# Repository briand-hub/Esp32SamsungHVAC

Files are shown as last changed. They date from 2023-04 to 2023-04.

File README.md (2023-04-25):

# Briand's SAMSUNG HVAC controller MWR-WH000

Open Source project under GPL3 [LICENSE](LICENSE).

No warranty on circuit or software, do it for educational puroposes. 

#### How to use?

Just edit [Settings](main/Settings.hxx) file entering your own SSID and Password, build circuit and cable and test. 
Always be safe when using electronics and power sources!

## Intro

Samsung MWR-WRH00 with wired remote wall mounted command (D64 type) needs to be wifi-enabled to use with HomeAssistant.

Found protocol on https://github.com/DannyDeGaspari/Samsung-HVAC-buscontrol

2-wire RS485 protocol. To open remote command simply push it up. Will find 4 pin connector (TYPE ????)

```
	male (to remote PCB) (* = attach clip, view from top)

	| | * | |
	| | * | |
	| | * | |
	 | | | |
     1 2 3 4

    female (from wall) (* = attach clip, view from top)

	| | | | |
	| | * | |
	| | * | |
	 1 2 3 4

	1) ORANGE wire, V1, +Vcc 12VDC 
	2) YELLOW wire, V2, GND
	3) RED wire, F3, RS485 port A
	4) BLUE wire, F4, RS485 port B
```

## Voltage adapter (12VDC to 5VDC)

Need to change 12V to 5.1V for ESP32 using zener diode. Circuit:

```
+12V o----| R |------*-------o +5.1V
					 |
					___
					/ \ Zener 5.1V
					 |
					 |
GND  o---------------*-------o GND
```

Calculations, known that ESP32 consumes about 240mA in active mode. Round to 300mA. Zener consumes about 5mA to work.
Voltage across R is Vr, voltage across zener is Vz = 5.1V
	Vr + Vz = 12V => Vr = 12-5.1 = 6.9V
	
R has voltage 6.9V and current is 305mA. So R = V/I = 6.9/0.305 = 22.6ohm so R = 22ohms according to standards. 
R should support 6.9V*0.305A = 2.1W
Zener should support  5.1V*0.305A = 1.55W

Other way: using 7805 regulator, supports up to 1A current.

```	 ________
	|	     |		1) Input, 12V
	| L7805  |		2) GND
	|________|		3) Output, 5V
	 |  |  |
	 |  |  |
	 |  |  |
     1  2  3

+12V o--->|----*---(1) 7805 (3)----*-----o +5V
		D1	   |	   (2)         |
			  ---		|         ---
			  ---C1	    |		  ---C2
			   |	    | 		   |
GND  o---------*--------*----------*-----o GND

```

D1 is 1N4007 (drops 0.6-1V) and helps 7805 work better. C1 is 10uF electrolitic and C2 is 1uF electrolitic (both 25V or C1 25V and C2 10V). Capacitors are **NOT OPTIONAL**.

**NOTE**: Tests shown a high temperature of 7805 reached after a while! Be careful and use a heat sink! Or pass by a 7809 before 7805 so dropped voltage transformed in heat will be less.

## ESP32 Pinout

ESP32 (WeMos Lolin D32) has 3 UARTs (UART0 is monitor, 1 free/unknown, 2 is completely free). IDF Framework based on FreeRTOS allows using an UART hardware port with *any* pin! However RS485 protocol is designed on RTS pin high (RequestToSend) when transmitting, so for this pin a low-level boot time pin is required. Chosen pins are:

GPIO17 as TX pin
GPIO18 as RTS pin
GPIO16 as RX pin

To change pins and port see main.cpp method Briand SamsungHvac->Initialize 
ESP32 will be a sniffer between machine and wired remote in order to be able to use both manual, wall mounted, remote and WiFi. Will need an RS485/TTL 5V converter (can find cheap on Amazon but I suggest to buy a DIP8 SN75176BP, I found that is the best one!).
Setup:

**Cable**

```
		| | | | 
		| | | | 
		| | | | 
		1 2 3 4
		| | | |
		o----------- Orange, V1, +12VDC ---> to 7805 input
		| o--------- Yellow, V2, GND    ---> to 7805 ground
		| | o------- Red, F3, Signal    ---> to A port on RS485/TTL
		| | | o----- Blue, F4, Signal   ---> to B port on RS485/TTL
		| | | |
		1 2 3 4
		| | | | 
 		| | | | 
 		| | | | 
```

## RS485/TTL to ESP32

```
Pin DI/R => to RX (ESP GPIO16)
Pin DE => to RTS  (ESP GPIO18)
Pin RE => to RTS (ESP GPIO18)
Pin RO/D => to TX (ESP GPIO17)

VCC => +5 VDC from 7805
GND => GND
A => cable (red) to A
B => cable (blue) to B
```

## Final circuit

#### Materials needed

* 1x Diode 1N4001 or 1N4007 (or 3x to decrease heat)
* 1x Voltage regulator with output of 5V (7805CV, LM2940CT5 or similar)
* ESP32 
* SN75176BP (best!) or MAX485
* 1x Electrolitic capacitor 10uF 
* 1x Electrolitic capacitor 1uF
* 1x heatsinker for TO-220 voltage regulator

Optional:

* 1x 3mm green Led 
* 1x 150ohm Resistor 
* TVS bipolar diode (RS485 IC input between port A to ground and between port B to ground for ESD/overvoltage protection)

See circuit in Fritzing model (Schema view) or the PNG file.

Calculations:

* LED 3mm green 2V 20mA 5V-2V = 3V and so R = V/I = 3V/0,02 = 150ohm with P = 3V*0,02 = 0,06WW

## Web server commands and API

**Parameters**

* temp : must be integer (ex. 22)
* mode : must be one of: "cool", "fan", "dry", "heat", "auto"
* fan : must be one of: "min", "max", "mid", "auto"
* power : must be "on" or "off"

**Get current HVAC status**

http://<IP>:<PORT>/

returns the current status in JSON

Response:

```
{ "power": "off", "mode": "cool", "temp": 24, "fan": "max", "ha_status": "OK", "ha_active": true }
```

**Change HVAC status**

http://<IP>:<PORT>/SetStatus?temp=<int>&mode=<mode>&fan=<fan>&power=<power>

Sample request/response:

```
http://<IP>:<PORT>/SetStatus?mode=cool&power=on
Power changed to ON
Mode changed to COOL
```

**Restart/reboot**

http://<IP>:<PORT>/RestartEsp

**Monitor log**

http://<IP>:<PORT>/Log

*not implemented yet*

## Test result

All commands are received/sent successfully. However sometimes an error E607 appears on the wall mounted remote when a command is sent and sometimes is not correctly applied.
Possible solutions:

* Setting RX buffer to 0 so no buffering will be made? *No, not allowed!*
* Adding 50ms delay before sending the message through serial when the "mark" is reached qould help? *Did not resolve*
* Play with rx threshold values? *Did not resolve*

On circuit L7805CV model seems to have lot of heat. Needs a heat sink. However another (and implemented solution) is to add 2 more 2N4001 in series to D1 in order to have a lower voltage in input. This solves the heat problem. 

Other unsuccessful test done was adding a 2-step LDO: L7809 before L7805 however this seems to led insufficient amperes to ESP32 meaning no working system at all.

## Protocol

RS485 Protocol description **CREDITS: https://github.com/DannyDeGaspari/Samsung-HVAC-buscontrol**. Took and reported there some needed texts.

*Serial communication settings used on the bus are 2400 baud, 8E1 **(8 bit, even parity, 1 bit stop)**. The wired remote control is the master, the indoor units are the slaves. The wired remote control send commands as a message of 14 bytes. The units respond with a similar message with the same length. The protocol can be described as follows:*

<start> <src> <dst> <cmd> <data: 8 bytes> <chksum> <end>

With:
Byte   Identifier   Comments
----------------------------
1      Start  : start of message (0x32)
2      Src    : Source address
3      Dst    : Destination address
4      Cmd    : Command byte
5-12   Data   : Data is always 8 bytes in length, unused bytes will be zero
13     Chksum : Checksum of message which is the XOR of bytes 2-12
14     End    : end of message (0x34)

*In my case the address of the wired remote control is 0x84* => **For me too!**
*the address of my 2 indoor units are 0x20 and 0x21* => **For me too! However I have just one, 0x20**

An example communication can look like this (all values are hex and xx represent any value):

```
Command:
32 84 20 53 xx xx xx xx xx xx xx xx xx 34
Reply:
32 20 84 53 xx xx xx xx xx xx xx xx xx 34
```

### Command tables

All values of the commands and bit group values in the following tables are in hexadecimal notation.
The bits that are not described in the following tables are zero and the function of those bits are unknown.

### Command A0

Change settings command, by exception the unit replies with command 50, all other commands are replied with the same command identifier.
This is the command to be used when the settings of the HVAC unit needs to be changed.

| Data byte | Settings |
| :---: | :--- |
| 1 | <p>bit 4-0 : 0x1a = blade swing up/down<br>0x1f = blade swing off</p> |
| | bit 5 : sleep |
| 2 | 0 |
| 3 | bit 4-0 : temperature setting |
| | <p>bit 7-5 : fan speed<br>0 = auto<br>2 = low<br>4 = medium<br>5 = high</p> |
| 4 | <p>bit 2-0 : mode<br>0 = auto<br>1 = cool<br>2 = dry<br>3 = fan<br>4 = heat</p> |
| | bit 5 : reset "clean filter" message |
| 5 | <p>bit 7-0 : on/off<br>c4 = switch off<br>f4 = switch on</p> |
| 6 | 0 |
| 7 | <p>bit 3-0 : set blade position<br>0 = closed<br>1 = open smallest<br>2 = mid positions<br>7 = open max</p> |
| | bit 4 : set blade position |
| | bit 5 : quiet mode |
| 8 | 0 |

### Command 52

This command is an information request. The bytes in the command are all zeroes, the reply to this command is described below:

| Data byte | Settings |
| :---: | :--- |
| 1 | bit 5-0 : set temperature - 9 |
| | bit 6 : always set to '1' ? |
| 2 | bit 5-0 : room temperature - 9 |
| | bit 6 : always set to '1' ? |
| 3 | bit 5-0 : output air temperature - 9 |
| | bit 6 : always set to '1' ? |
| 4 | <p>bit 2-0 : fan speed<br>0 = auto<br>2 = low<br>4 = medium<br>5 = high</p> |
| | <p>bit 7-3 : blade swing<br>1A = swing up/down<br>1F = blade swing off</p> |
| 5 | <p>bit 3-0 : 1 = wired control<br>2 = remote control</p> |
| | bit 4 : 1 = defrost on |
| | <p>bit 7 : 0 = power is off<br>1 = power in on</p> |
| 6 | bit 4 : 1 = filter needs cleaning |
| 7 | 0 |
| 8 | bit 5-0 : another temperature - 9 |
| | bit 6 : always set to '1' ? |

### Command 53

This command is an information request. The bytes in the command are all zeroes, the reply to this command is described below:

| Data byte | Settings |
| :---: | :--- |
| 1 | 0 |
| 2 | 0 |
| 3 | 0 |
| 4 | 0 |
| 5 | <p>bit 7-0 : 0 = blade swing off<br>1A = blade swing up/down</p> |
| 6 | 0 |
| 7 | 0 |
| 8 | <p>bit 2-0 : mode<br>0 = auto<br>1 = cool<br>2 = dry<br>3 = fan<br>4 = heat</p> |

### Command 54

This command is an information request. The bytes in the command are all zeroes, the reply to this command is described below:

| Data byte | Settings |
| :---: | :--- |
| 1 | contains value 21, meaning unknown |
| 2 | <p>bit 3-0 : blade position when swing is off<br>0 = closed<br>1 = open smallest<br>2 = mid positions<br>7 = open max</p> |
| | <p>bit 4 : 0 = blade swing off<br>1 = blade swing up/down</p> |
| 3 | 1E : meaning unknown |
| 4 | 0 |
| 5 | 0 |
| 6 | unknown |
| 7 | 0 |
| 8 | 0 |

### Command 64

This command is the temperature information command to the unit, the reply to this command is described below:

| Data byte | Settings |
| :---: | :--- |
| 1 | contains value 20 for command and reply, meaning unknown |
| 2 | <p> command and reply: bit 0: used temperature for regulation<br>0 = use internal temperature<br>1= use wired remote temperature</p> |
| 3 | command: wired remote temperature value high byte |
| | reply: used temperature value high byte |
| 4 | command: wired remote temperature value low byte |
| | reply: used temperature value low byte |
| 5 | reply: unit temperature value high byte |
| 6 | reply: unit temperature value low byte |
| 7 | 0 |
| 8 | 0 |

The temperature in degrees is calculated as follows: 
```
(<high byte> * 256 + <low byte> - 553) / 10
```

### Other commands

Other commands seen on the link are: 63, 70, 71, 83, D1.
The meaning of these commands and replies are unknown.
Be careful with trying other commands because it is possible that there exist commands that have impact on the flash memory contents of the unit and may brick the memory contents of the unit.

## Circuit schema and picture

Circuit schematics

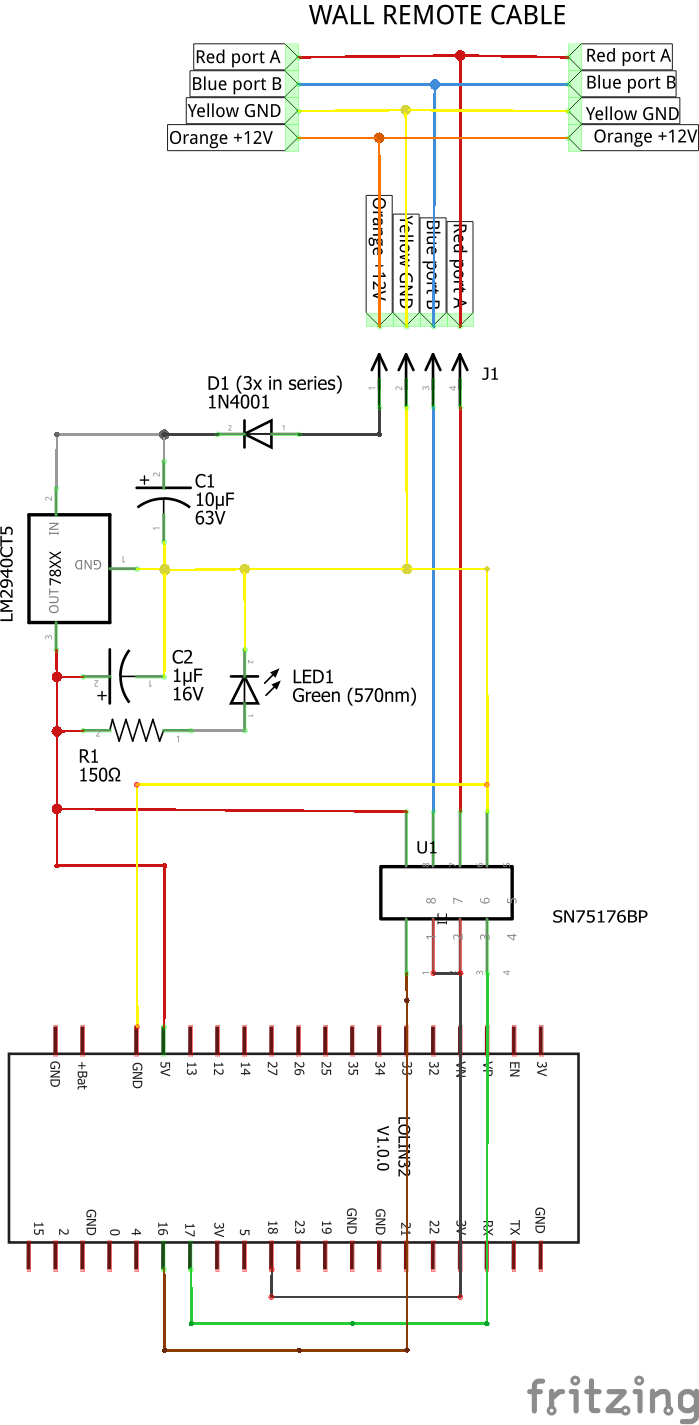
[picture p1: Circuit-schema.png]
Circuit diagram


The first working prototype

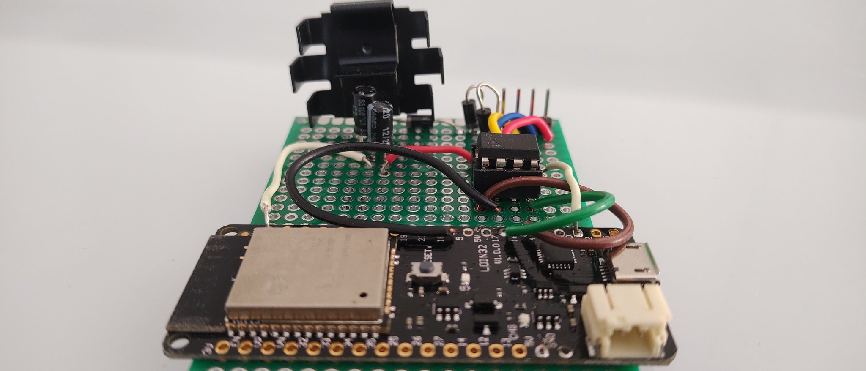
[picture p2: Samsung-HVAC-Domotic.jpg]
Demo


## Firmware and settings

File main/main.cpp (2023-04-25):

/** Copyright (C) 2023 briand (https://github.com/briand-hub)

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
    You should have received a copy of the GNU General Public License
    along with this program.  If not, see <http://www.gnu.org/licenses/>.
*/

#include "Common.hxx"
#include "BriandLibEsp32IDF.hxx"
#include "BriandSamsungHvac.hxx"
#include "Settings.hxx"

/* Early declarations */
void SerialReadWriteTask(void* taskArg);
esp_err_t ServeStatus(httpd_req_t* req);
esp_err_t ServeSetStatus(httpd_req_t* req);
esp_err_t ServeRestart(httpd_req_t* req);
void Reboot();

/* Declarations */

const httpd_uri uriStatus {
	.uri = "/",
	.method = HTTP_GET,
	.handler = ServeStatus
};

const httpd_uri uriSetStatus {
	.uri = "/SetStatus",
	.method = HTTP_GET,
	.handler = ServeSetStatus
};

const httpd_uri uriRestart {
	.uri = "/RestartEsp",
	.method = HTTP_GET,
	.handler = ServeRestart
};

httpd_handle_t serverHandle = NULL;
TaskHandle_t serialTaskHandle = NULL;
TaskHandle_t wifiTaskHandle = NULL;
unique_ptr<Briand::SamsungHvac> SamsungHvac = nullptr;
unique_ptr<Briand::WifiManager> wifi = nullptr;

const esp_vfs_spiffs_conf_t spiffsConfiguration = {
	.base_path = "/spiffs",
	.partition_label = NULL,
	.max_files = 5,
	.format_if_mount_failed = true
};

/********************************************/
/*					PROGRAM					*/
/********************************************/

// Required extern "C" for C++ use WITH IDF!
extern "C" void app_main() {
	try {
		// Set BuiltIn LED 
		gpio_set_direction(GPIO_NUM_5, GPIO_MODE_OUTPUT);

		// UNbuffer stdout
		setvbuf(stdout, NULL, _IONBF, 0);

		// Common for error testing
		esp_err_t ret;

		// Initialize the NVS
		ESP_LOGI(LOG_TAG, "Initializing NVS");

		ret = nvs_flash_init();
		if (ret == ESP_ERR_NVS_NO_FREE_PAGES || ret == ESP_ERR_NVS_NEW_VERSION_FOUND) {
			ESP_ERROR_CHECK(nvs_flash_erase());
			ret = nvs_flash_init();
		}
		ESP_ERROR_CHECK(ret);
		ESP_LOGI(LOG_TAG, "NVS Initialized.");

		// Initialize SPIFFS
		ESP_LOGI(LOG_TAG, "Initializing SPIFFS");

		// Use settings defined above to initialize and mount SPIFFS filesystem.
		// Note: esp_vfs_spiffs_register is an all-in-one convenience function.
		ret = esp_vfs_spiffs_register(&spiffsConfiguration);
		if (ret == ESP_OK) {
			ESP_LOGI(LOG_TAG, "SPIFFS Initialized.");
		}
		else {
			ESP_LOGE(LOG_TAG, "**** SPIFFS initialization failed! ERROR is: %s", esp_err_to_name(ret));
		}

		// Initialize WiFi handler
		wifi = make_unique<Briand::WifiManager>();
		wifi->ConnectStation(WIFI_ESSID, WIFI_PASSW);

		// Start web server
		ESP_LOGI(LOG_TAG, "Starting WebServer on port %d", WEB_SERVER_PORT);
		httpd_config serverConfig = HTTPD_DEFAULT_CONFIG();
		serverConfig.server_port = WEB_SERVER_PORT;
		serverConfig.stack_size = WEB_SERVER_STACK;
		serverConfig.lru_purge_enable = true;
		ret = httpd_start(&serverHandle, &serverConfig);
		if (ret == ESP_OK) {
			// Set URI handlers
			ESP_LOGI(LOG_TAG, "Registering URI handlers");
			httpd_register_uri_handler(serverHandle, &uriStatus);
			httpd_register_uri_handler(serverHandle, &uriSetStatus);
			httpd_register_uri_handler(serverHandle, &uriRestart);
		}
		else {
			ESP_LOGE(LOG_TAG, "**** Failed to start WebServer! ERROR IS: %s", esp_err_to_name(ret));
		}

		ESP_LOGI(LOG_TAG, "Starting Serial");
		
		SamsungHvac = make_unique<Briand::SamsungHvac>();
		SamsungHvac->Initialize(UART_NUM_2, 0, GPIO_NUM_17, GPIO_NUM_16, GPIO_NUM_18, UART_PIN_NO_CHANGE);
		ESP_LOGI(LOG_TAG, "Serial ready.");

		// Start task for serial read/write with max priority in specific core
		xTaskCreatePinnedToCore(SerialReadWriteTask, "SerialTask", 4096, NULL, 1, &serialTaskHandle, 1);
	} 
	catch(const exception& e) {
		ESP_LOGE(LOG_TAG, "**** Exception caught: %s\n", e.what());
	}

	fflush(stdout);
}

esp_err_t ServeStatus(httpd_req_t* req) {
	httpd_resp_set_type(req, "application/json");
	
	auto currentStatus = SamsungHvac->GetSamsungStatus();
	char conversionBuffer[3];

	unique_ptr<string> json = make_unique<string>();
	json->append("{ ");
	json->append("\"power\": \"");
	json->append(Briand::SamsungHvac::PowerToString(currentStatus.Power));
	json->append("\", \"mode\": \"");
	json->append(Briand::SamsungHvac::ModeToString(currentStatus.Mode));
	json->append("\", \"temp\": ");
	json->append(itoa(currentStatus.Temperature, conversionBuffer, 10));
	json->append(", \"fan\": \"");
	json->append(Briand::SamsungHvac::FanSpeedToString(currentStatus.Fan));

	// some vars that helps in HomeAssistant
	json->append("\", \"ha_status\": \"OK\", \"ha_active\": true");

	json->append(" }");

	return httpd_resp_send(req, json->c_str(), json->length());
}

void SerialReadWriteTask(void* taskArg) {
	while (1) {
		SamsungHvac->DoSerialWork();
		vTaskDelay(50 / portTICK_PERIOD_MS);
	}
}

esp_err_t ServeSetStatus(httpd_req_t* req) {
	httpd_resp_set_hdr(req, "Content-Type", "text/plain");
	httpd_resp_set_status(req, "200 OK");

	// Get current status
	auto newStatus = SamsungHvac->GetSamsungStatus();
	
	// Get query params and change the status
	int qsBufLen = httpd_req_get_url_query_len(req) + 1;
	char qsBuffer[qsBufLen];

	if (httpd_req_get_url_query_str(req, qsBuffer, qsBufLen) != ESP_OK) {
		httpd_resp_set_type(req, "text/plain");
		return httpd_resp_send(req, "No argument received!", strlen("No argument received!"));
	}

	char param[32] = { 0 };

	if (httpd_query_key_value(qsBuffer, "power", param, sizeof(param)) == ESP_OK) {
		if (strcmp(param, "on") == 0) {
			newStatus.Power = Briand::SamsungHvacPower::On; 
			httpd_resp_sendstr_chunk(req, "Power changed to ON\r\n");
		} 
		else if (strcmp(param, "off") == 0) {
			newStatus.Power = Briand::SamsungHvacPower::Off;
			httpd_resp_sendstr_chunk(req, "Power changed to OFF\r\n");
		}
		else {
			httpd_resp_sendstr_chunk(req, "Power INVALID! valid values = on|off but received = ");
			httpd_resp_sendstr_chunk(req, param);
			httpd_resp_sendstr_chunk(req, "\r\n");
		}
	}

	bzero(static_cast<void*>(param), 32);

	if (httpd_query_key_value(qsBuffer, "fan", param, sizeof(param)) == ESP_OK) {
		if (strcmp(param, "auto") == 0) {
			newStatus.Fan = Briand::SamsungHvacFanSpeed::FanAuto;
			httpd_resp_sendstr_chunk(req, "Fan changed to AUTO\r\n");
		} 
		else if (strcmp(param, "max") == 0) {
			newStatus.Fan = Briand::SamsungHvacFanSpeed::FanMax;
			httpd_resp_sendstr_chunk(req, "Fan changed to MAX\r\n");
		} 
		else if (strcmp(param, "mid") == 0) {
			newStatus.Fan = Briand::SamsungHvacFanSpeed::FanMid;
			httpd_resp_sendstr_chunk(req, "Fan changed to MID\r\n");
		} 
		else if (strcmp(param, "min") == 0) {
			newStatus.Fan = Briand::SamsungHvacFanSpeed::FanMin;
			httpd_resp_sendstr_chunk(req, "Fan changed to MIN\r\n");
		} 
		else {
			httpd_resp_sendstr_chunk(req, "Fan INVALID! valid values = auto|max|mid|min but received = ");
			httpd_resp_sendstr_chunk(req, param);
			httpd_resp_sendstr_chunk(req, "\r\n");
		}
	}

	bzero(static_cast<void*>(param), 32);

	if (httpd_query_key_value(qsBuffer, "mode", param, sizeof(param)) == ESP_OK) {
		if (strcmp(param, "auto") == 0) {
			newStatus.Mode = Briand::SamsungHvacMode::Auto;
			httpd_resp_sendstr_chunk(req, "Mode changed to AUTO\r\n");
		} 
		else if (strcmp(param, "cool") == 0) {
			newStatus.Mode = Briand::SamsungHvacMode::Cool;
			httpd_resp_sendstr_chunk(req, "Mode changed to COOL\r\n");
		} 
		else if (strcmp(param, "dry") == 0) {
			newStatus.Mode = Briand::SamsungHvacMode::Dry;
			httpd_resp_sendstr_chunk(req, "Mode changed to DRY\r\n");
		} 
		else if (strcmp(param, "fan") == 0) {
			newStatus.Mode = Briand::SamsungHvacMode::Fan;
			httpd_resp_sendstr_chunk(req, "Mode changed to FAN\r\n");
		} 
		else if (strcmp(param, "heat") == 0) {
			newStatus.Mode = Briand::SamsungHvacMode::Heat;
			httpd_resp_sendstr_chunk(req, "Mode changed to HEAT\r\n");
		} 
		else {
			httpd_resp_sendstr_chunk(req, "Mode INVALID! valid values = auto|cool|dry|heat|fan but received = ");
			httpd_resp_sendstr_chunk(req, param);
			httpd_resp_sendstr_chunk(req, "\r\n");
		}
	}

	bzero(static_cast<void*>(param), 32);

	if (httpd_query_key_value(qsBuffer, "temp", param, sizeof(param)) == ESP_OK) {
		int temp = atoi(param);
		if (temp >= 0 && temp <= 40) {
			newStatus.Temperature = temp;
			httpd_resp_sendstr_chunk(req, "Temperature changed to: ");
			char ntBuf[16] = { 0 };
			itoa(temp, ntBuf, 10);
			httpd_resp_sendstr_chunk(req, ntBuf);
			httpd_resp_sendstr_chunk(req, "\r\n");
		}
		else {
			httpd_resp_sendstr_chunk(req, "Temperature INVALID! valid values = <int> but received = ");
			httpd_resp_sendstr_chunk(req, param);
			httpd_resp_sendstr_chunk(req, "\r\n");
		}
	}
	
	SamsungHvac->RequestSamsungChangeStatus(newStatus);

	//return httpd_resp_send(req, NULL, 0);
	return httpd_resp_sendstr_chunk(req, NULL);
}

esp_err_t ServeRestart(httpd_req_t* req) {
	httpd_resp_set_type(req, "text/plain");
	httpd_resp_send(req, "REBOOTING!", strlen("REBOOTING!"));
	httpd_resp_send(req, NULL, 0);
	Reboot();

	return ESP_OK;
}

void Reboot() {
	ESP_LOGI(LOG_TAG, "\n\n### Restarting ESP.\n\n");
	try {
		ESP_LOGI(LOG_TAG, "### Stopping serial...");
		if (serialTaskHandle != NULL) vTaskDelete(serialTaskHandle);
		SamsungHvac.reset();
		ESP_LOGI(LOG_TAG, "### Stopping wifi...");
		if (wifiTaskHandle != NULL) vTaskDelete(wifiTaskHandle);
		if (wifi != nullptr) wifi->DisonnectStation();
		ESP_LOGI(LOG_TAG, "### Stopping webserver...");
		if (serverHandle != NULL && httpd_stop(serverHandle) != ESP_OK) ESP_LOGW(LOG_TAG, "**** Stopping webserver failed!");
	}
	catch(const exception& e) {
		ESP_LOGE(LOG_TAG, "**** Exception caught while restarting: %s\n", e.what());
	}

	ESP_LOGI(LOG_TAG, "### Restarting in 1 second.");
	fflush(stderr);
	fflush(stdout);
	vTaskDelay(1000 / portTICK_PERIOD_MS);

	esp_restart();
}

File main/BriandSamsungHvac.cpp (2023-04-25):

/** Copyright (C) 2023 briand (https://github.com/briand-hub)

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
    You should have received a copy of the GNU General Public License
    along with this program.  If not, see <http://www.gnu.org/licenses/>.
*/

#include "BriandSamsungHvac.hxx"

/** SamsungHvacState class **/

Briand::SamsungHvacState::SamsungHvacState() {
	this->Fan = Briand::SamsungHvacFanSpeed::UNKNOWN;
	this->Mode = Briand::SamsungHvacMode::UNKNOWN;
	this->Power = Briand::SamsungHvacPower::UNKNOWN;
	this->Temperature = 0x00;
}

/** SamsungHvac class **/

Briand::SamsungHvac::SamsungHvac() {
	this->_stateChangeQueue = make_unique<queue<Briand::SamsungHvacState>>();
	this->_currentState = make_unique<Briand::SamsungHvacState>();
	this->_uartPort = UART_NUM_2;
}

Briand::SamsungHvac::~SamsungHvac() {
	// Wait for a mutex
	unique_lock<mutex> locker(this->_mutexStatus);
	this->_currentState.reset();

	// Wait for a mutex
	unique_lock<mutex> locker2(this->_mutexQueue);
	this->_stateChangeQueue.reset();
	
	// Uninstall driver and release UART port
	if (uart_is_driver_installed(this->_uartPort)) {
		uart_flush(this->_uartPort);
		uart_flush_input(this->_uartPort);
		uart_driver_delete(this->_uartPort);
	}
}

void Briand::SamsungHvac::Initialize(
	const uart_port_t& port /* = UART_NUM_2 */
	, const int& initrAllocFlags /* = 0 */
	, const int& txPin /* = UART_PIN_NO_CHANGE */
	, const int& rxPin /* = UART_PIN_NO_CHANGE */
	, const int& rtsPin /* = UART_PIN_NO_CHANGE */
	, const int& ctsPin /* = UART_PIN_NO_CHANGE */
	, const string& spiffsLogFilePath /* = "" */
) {
	this->_logFileName = spiffsLogFilePath;

	// Prepare configuration for Samsung Hvac. 
	// Baud is 2400, 8 bit data, partity even, 1 bit stop
	const uart_config_t uartConfiguration = {
		.baud_rate = 2400,							// Samsung HVAC default RS485 Baud rate
		.data_bits = UART_DATA_8_BITS,				// 8 bit data
		.parity = UART_PARITY_EVEN,					// Parity even
		.stop_bits = UART_STOP_BITS_1,				// 1 stop bit
		.flow_ctrl = UART_HW_FLOWCTRL_DISABLE,		// took from ESP IDF docs and samples
		.rx_flow_ctrl_thresh = 14,					// should not be necessary with no hw flow control...
		.source_clk = UART_SCLK_APB					// meaning default value
	};

	this->_uartPort = port;

	ESP_LOGI("Briand::SamsungHvac", "Installing UART driver on port %d", port);

	// According to documentation and example RX bufsize is 127*2 (?? with other values is not working) and TX has no buffer
	ESP_ERROR_CHECK(uart_driver_install(port, 127*2, 0, 0, NULL, initrAllocFlags));
	ESP_ERROR_CHECK(uart_param_config(port, &uartConfiguration));

	// PIN Setting
	ESP_ERROR_CHECK(uart_set_pin(port, txPin, rxPin, rtsPin, ctsPin));
	ESP_LOGI("Briand::SamsungHvac", "UART driver installed on port %d with pins (TX,RX,RTS,CTS) = (%d,%d,%d,%d)", port, txPin, rxPin, rtsPin, ctsPin);

	// Set RS485 half duplex mode
    ESP_ERROR_CHECK(uart_set_mode(port, UART_MODE_RS485_HALF_DUPLEX));
	ESP_LOGI("Briand::SamsungHvac", "UART%d in RS485 HalfDuplex mode", port);

    // Set read timeout of UART TOUT feature
    ESP_ERROR_CHECK(uart_set_rx_timeout(port, 3)); // 3.5T * 8 = 28 ticks, TOUT=3 -> ~24..33 ticks
	ESP_LOGI("Briand::SamsungHvac", "UART%d with rx timeout set to 3.", port);

	ESP_LOGI("Briand::SamsungHvac", "UART%d READY!", port);
}

const Briand::SamsungHvacState Briand::SamsungHvac::GetSamsungStatus() {
	SamsungHvacState state;

	// Wait for a mutex
	unique_lock<mutex> locker(this->_mutexStatus);

	state.Power = this->_currentState->Power;
	state.Fan = this->_currentState->Fan;
	state.Mode = this->_currentState->Mode;
	state.Temperature = this->_currentState->Temperature;

	return state;
}

void Briand::SamsungHvac::RequestSamsungChangeStatus(const SamsungHvacState& newState) {
	// Wait for a mutex
	unique_lock<mutex> locker(this->_mutexQueue);

	// Add to the queue
	this->_stateChangeQueue->push(newState);

	ESP_LOGI("Briand::SamsungHvac", "New status requested. Queue length is %d", this->_stateChangeQueue->size());
}

unsigned char Briand::SamsungHvac::GetMessageChecksum(const unsigned char* message) {
	unsigned char checksum = 0x00;

	// Checksum is the XOR from bytes 2 to 12.
	// Message is missing START so checksum will be calculated from index 0 to 10 (included)

	for (unsigned char i = 0; i < 11; i++) {
        checksum ^= message[i];
    }

	return checksum;
}

const char* Briand::SamsungHvac::FanSpeedToString(const Briand::SamsungHvacFanSpeed& speed) {
	switch (speed)
	{
		case Briand::SamsungHvacFanSpeed::FanAuto : return "auto";
		case Briand::SamsungHvacFanSpeed::FanMax : return "max";
		case Briand::SamsungHvacFanSpeed::FanMid : return "mid";
		case Briand::SamsungHvacFanSpeed::FanMin : return "min";
		default: return "???";
	}
}

const char* Briand::SamsungHvac::ModeToString(const Briand::SamsungHvacMode& mode) {
	switch (mode)
	{
		case Briand::SamsungHvacMode::Auto : return "auto";
		case Briand::SamsungHvacMode::Cool : return "cool";
		case Briand::SamsungHvacMode::Dry : return "dry";
		case Briand::SamsungHvacMode::Fan : return "fan";
		case Briand::SamsungHvacMode::Heat : return "heat";
		default:  return "???";
	}
}

const char* Briand::SamsungHvac::PowerToString(const Briand::SamsungHvacPower& power) {
	switch (power)
	{
		case Briand::SamsungHvacPower::On : return "on";
		case Briand::SamsungHvacPower::Off : return "off";
		default:  return "???";
	}
}
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

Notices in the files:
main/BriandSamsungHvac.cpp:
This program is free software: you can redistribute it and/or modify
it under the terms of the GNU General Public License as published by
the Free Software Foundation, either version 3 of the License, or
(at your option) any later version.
